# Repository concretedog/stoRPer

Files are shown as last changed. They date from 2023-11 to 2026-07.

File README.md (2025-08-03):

# 

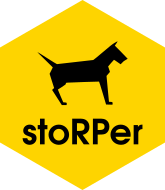
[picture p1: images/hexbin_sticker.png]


stoRPer, a modular adaptable AWD Pico based robot rover

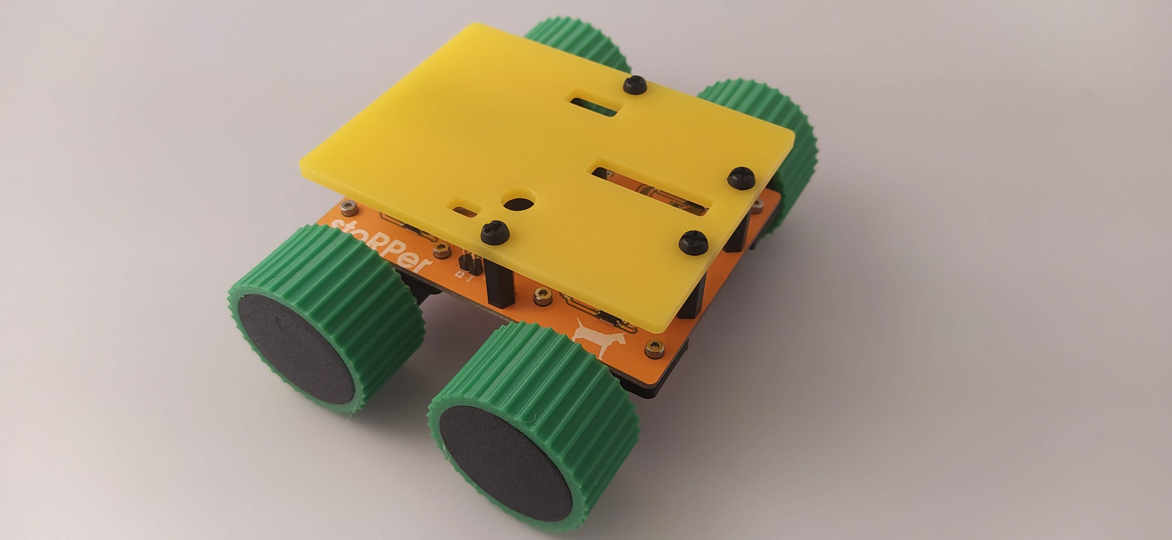
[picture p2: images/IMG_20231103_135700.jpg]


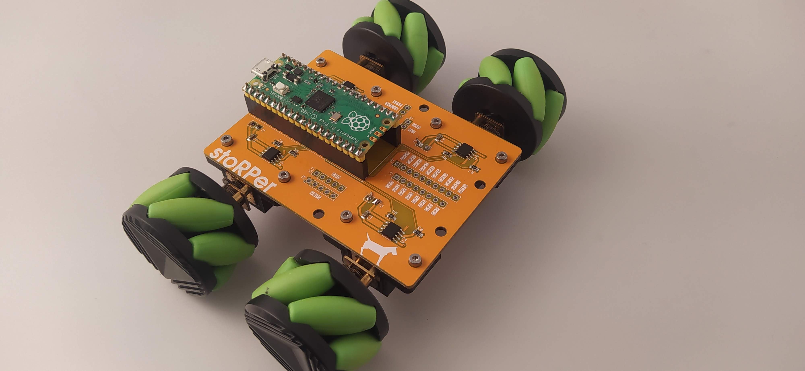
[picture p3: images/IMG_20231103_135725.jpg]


[Check out the youtube video](https://youtu.be/Y8ddx1Og3Xw?feature=shared) with details about the design and the design thinking, at the moment it's probably the best documentation! 

Basic Bill Of Materials, This is just a guide for a basic build as you could build up the PCB in any way you can imagine!

- The PCB, Available on [Tindie](https://www.tindie.com/products/concreted0g/storper/)
- 4* N20 metal gear motors in a gear ratio of your choice rated up to 6V. <br />
- 4* 3D printed motor mount clips to attach the motors (files in the 3D models section or periodically available on the tindie listing as an options)<br />
- 8* 6mm M2 bolts and nuts to attach motor mounts.<br />
- A raspberry pi Pico or Pico W, or equivalent footprint microcontroller board.<br />
- Some N20 compatible wheels (either commercial or home brew/3D printed)<br />
- Some kind of power supply (simplest is a small USB pack, other options are a 14500 or 18650 cell wired into the power input)<br />
- Semi optional, an upper deck to attach power supply too. (Inkscape files for Lasercutting or CNC or heck, cutting out with a saw, are in the Deck Drawing folder, or available lasercut on the Tindie listing)<br />

But that's just a guide, you could use different items or design to the basic PCB/chassis in different ways. <br />

All the KiCad files in the repo were originally made in version 7.xx. 

**Update 28-05-2024**

Added an Addons folder which currently contains 2 new PCB designs. <br />

Bumper can receive an ultrasonic module (HC-SR04) and also have 2 bump switches connected. <br />
The Kludge Deck conforms to the StoRPer main PCB layout with lots of prototyping space and extra holes for mounting stuff! <br />

Bumpers can be added above or below the main PCB with lots of different mount options. Therefore you might need to buy a range of standoffs to accomodate and support your design. If however you have access to a 3D printer there is a FreeCAD file in the 3D models section called STANDOFFS which you can simply adjust the length of a standoff tube that will slot over an M3 bolt. You can make custom lengths to suit your build. 

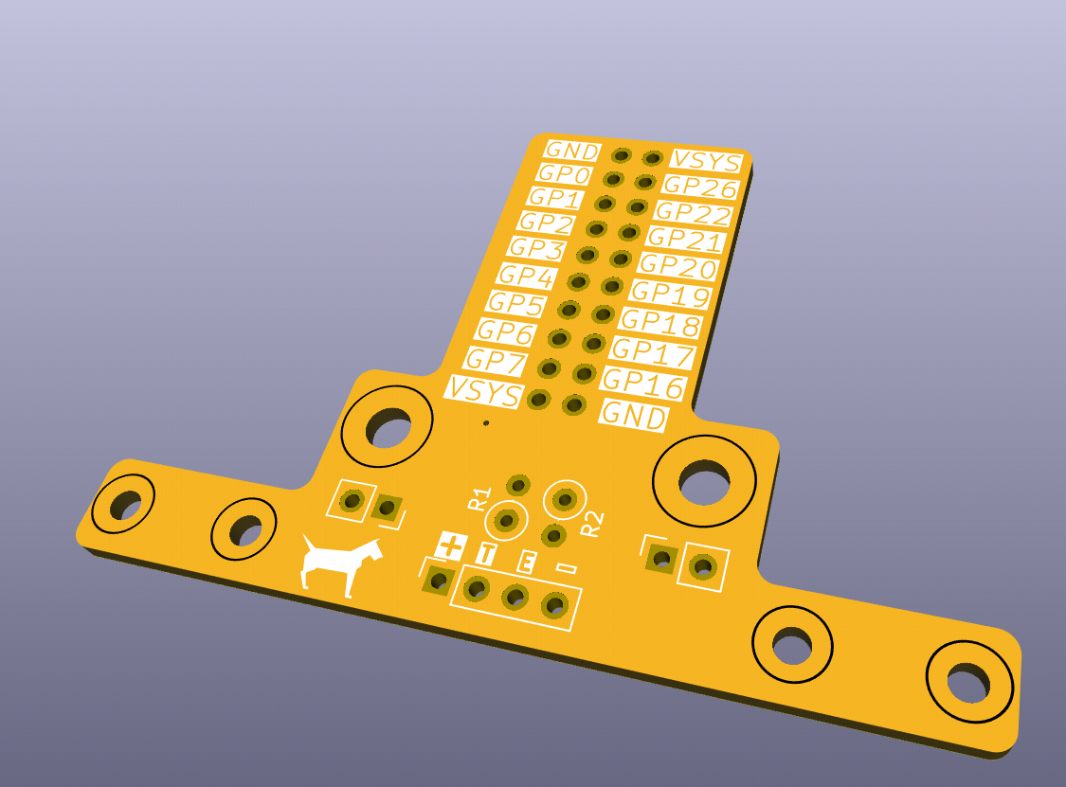
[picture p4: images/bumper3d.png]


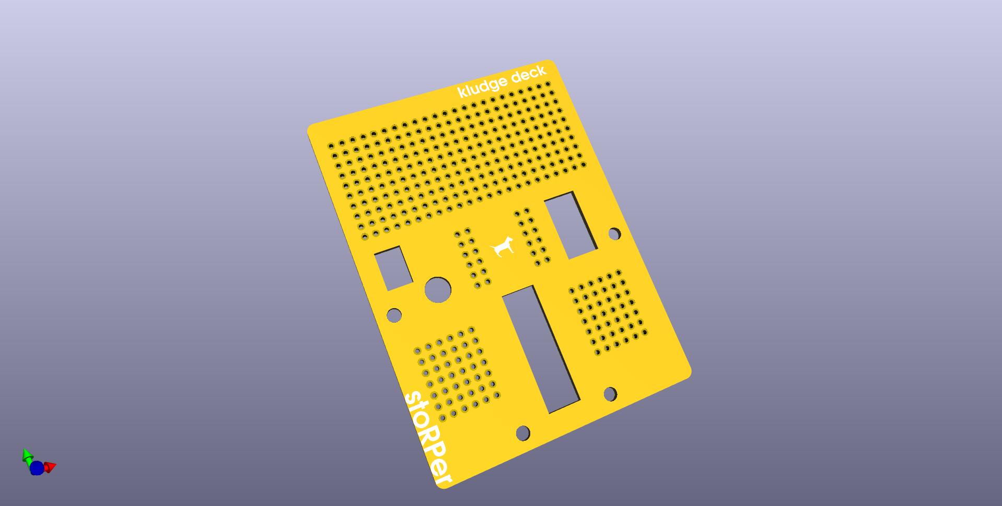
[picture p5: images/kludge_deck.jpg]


**Tiny Update 29-06-25**

Added a small hex adaptor part to the 3D models section. I ran a workshop recently and wanted to use more affordable mecanum wheels and found some cheap 48mm mecanum wheels available on places like aliexpress etc. However they have a hexagonal axle mount. After numerous iterations and dialling in the 3D printing I made a super simple slip on adaptor part that sits inside the wheel and slots on snugly to the N20 motor mount. Useful for stoRPer of course, but useful for any N20 motor project. 

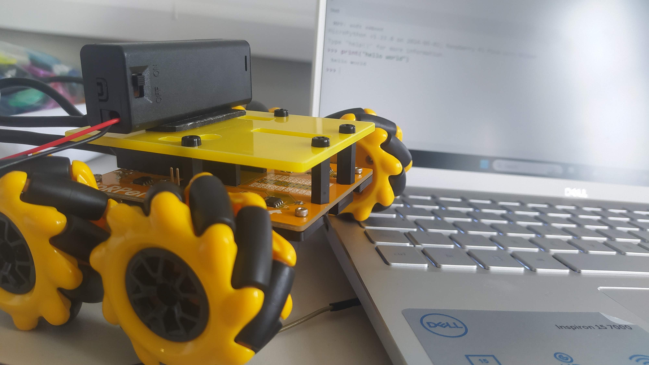
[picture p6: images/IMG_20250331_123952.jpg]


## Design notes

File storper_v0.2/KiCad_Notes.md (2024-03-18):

KiCad design originally made in version 7.xx <br />
In the main project the motor drivers are placed in hierarchical sheets. This is as I was writing a tutorial on Hierarchical sheets at the time!<br />
In the schmatics.pdf the Motor driver sections are all in the main sheet for easier reading. <br />

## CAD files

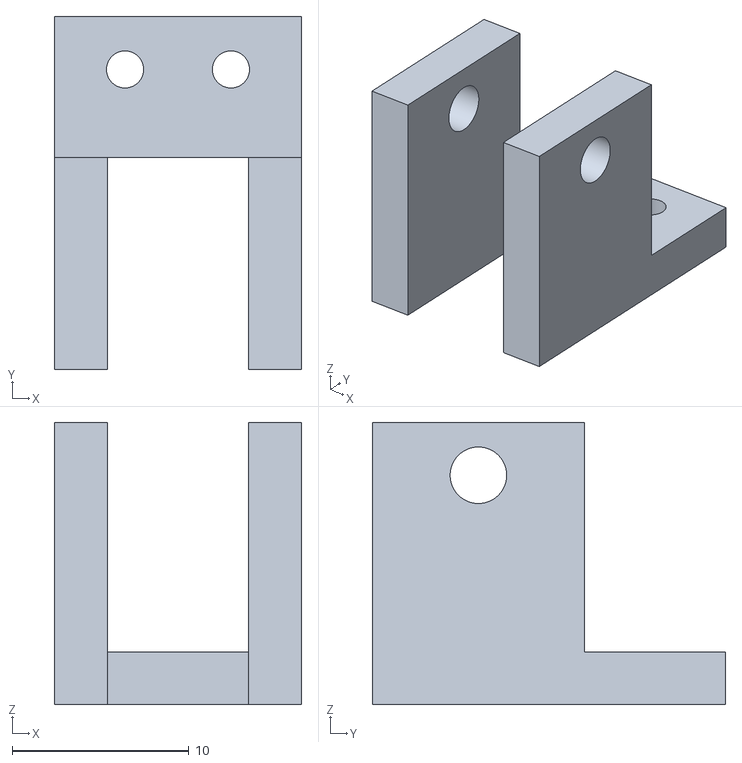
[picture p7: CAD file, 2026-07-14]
3D_Models/storper_tripod_rear_bracket.stl
14.0 x 20.0 x 16.0

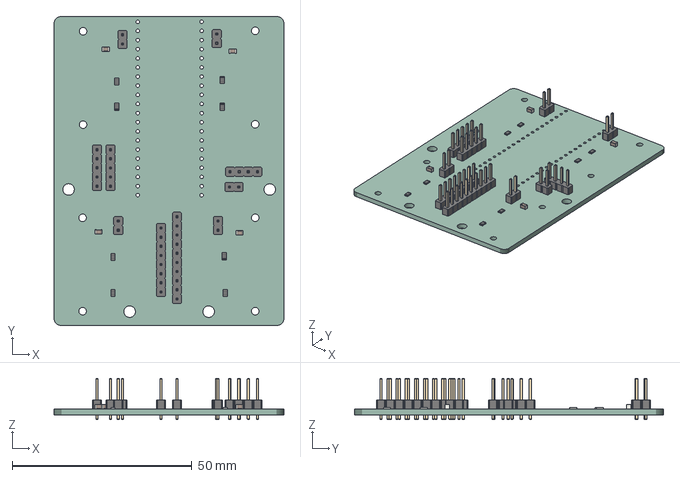
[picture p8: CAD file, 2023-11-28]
storper_v0.2/storper_v0.2.step
64.0 x 86.0 x 11.5 mm
storper_breakout PCB

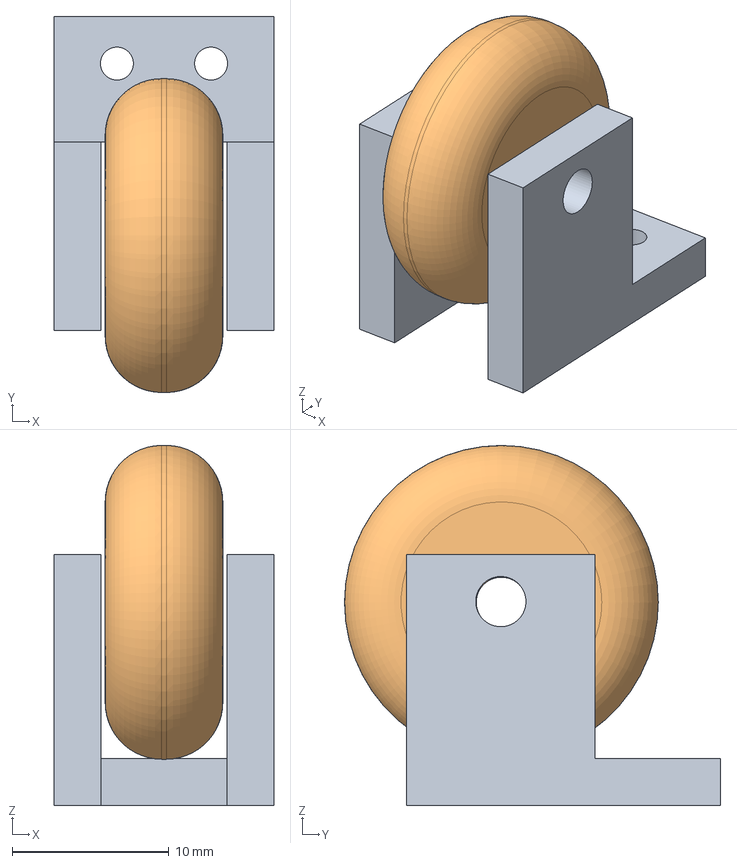
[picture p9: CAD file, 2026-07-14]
3D_Models/storper_tripod_rear_wheel.FCStd
14.0 x 24.0 x 23.0 mm

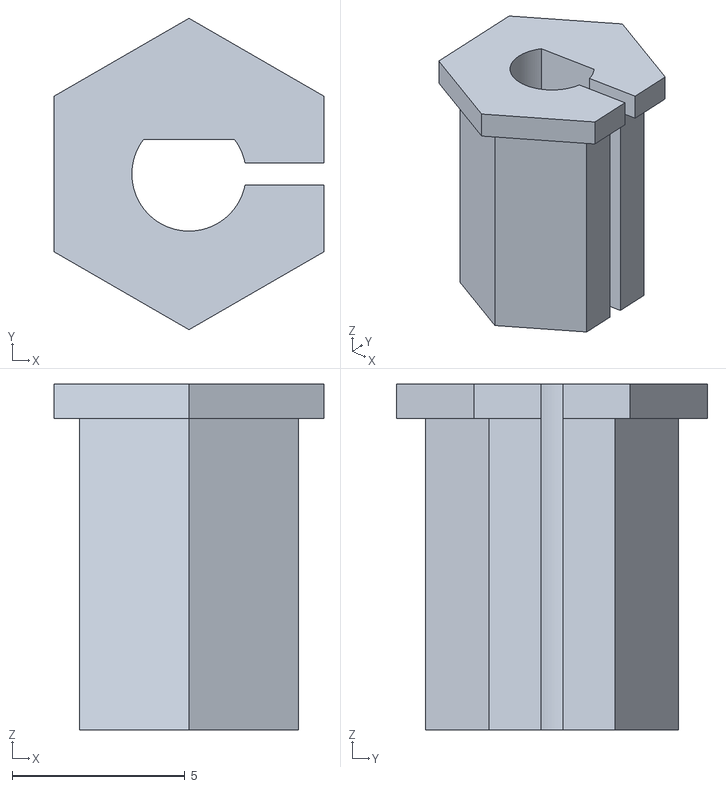
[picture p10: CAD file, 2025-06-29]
3D_Models/hex_wheeladaper.stl
7.79 x 9.00 x 10.0

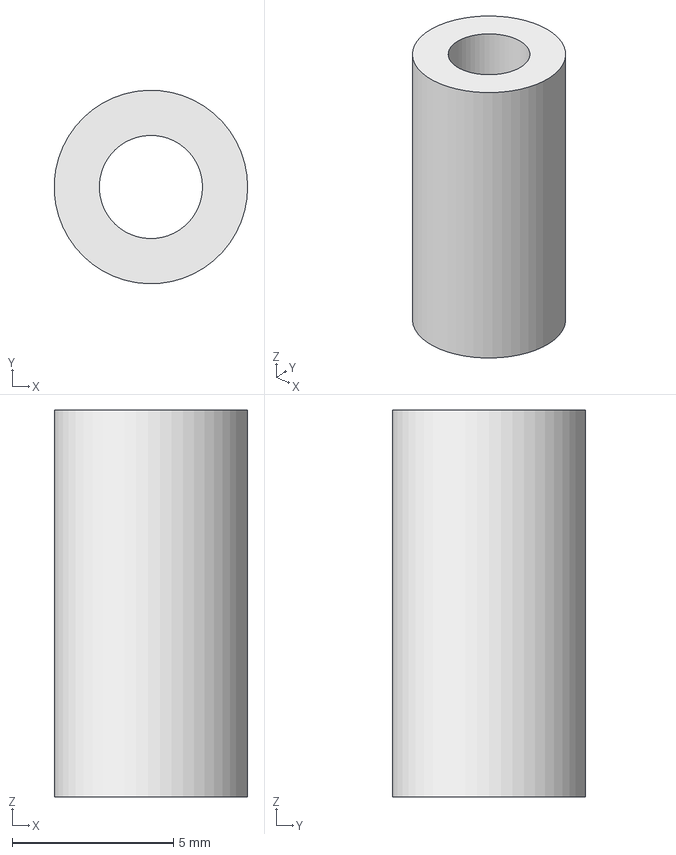
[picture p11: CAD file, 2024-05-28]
3D_Models/STANDOFF.FCStd
5.99 x 6.00 x 12.0 mm

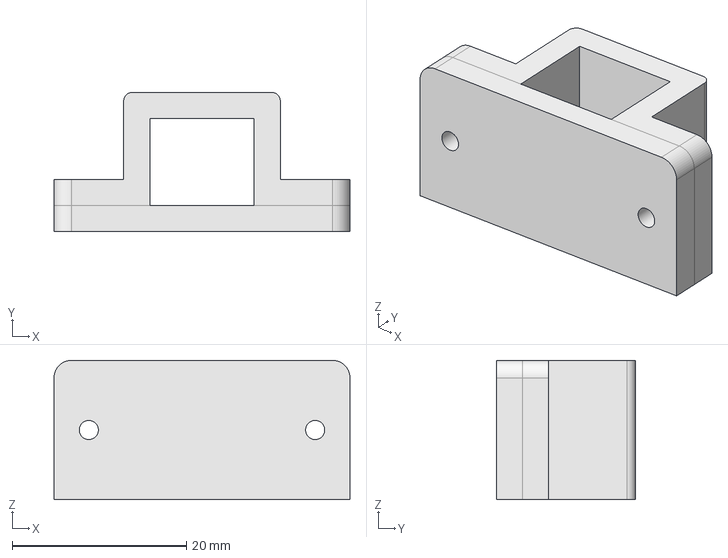
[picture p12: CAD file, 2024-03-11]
3D_Models/standoff_N20_Motor_clamp_TPU.FCStd
34.0 x 16.0 x 16.0 mm

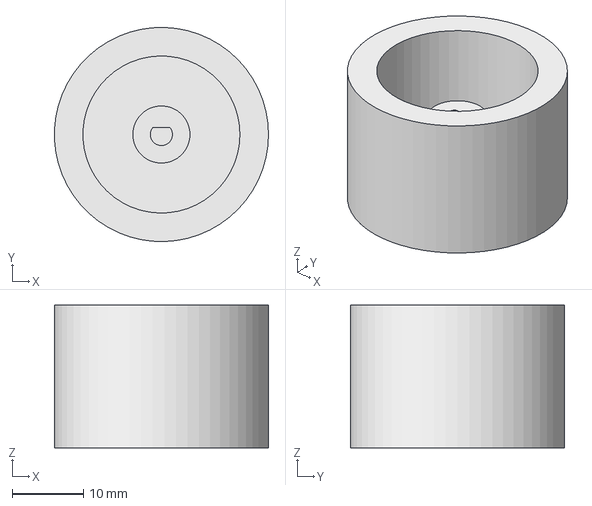
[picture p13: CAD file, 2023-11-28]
3D_Models/storper_standard_wheel.FCStd
30.0 x 30.0 x 20.0 mm

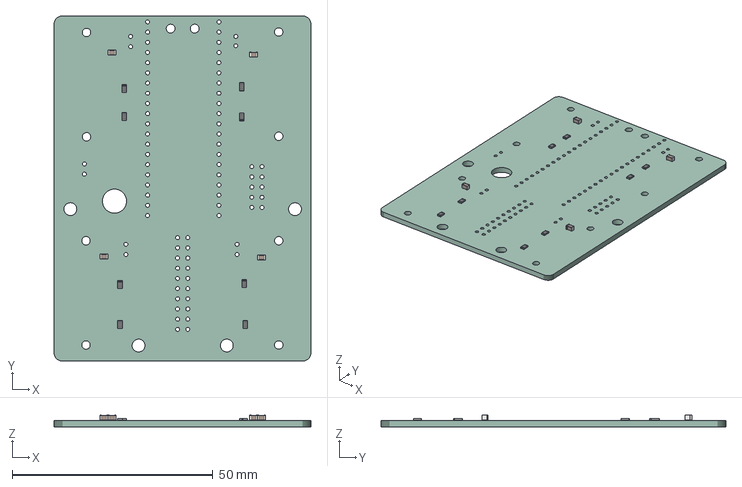
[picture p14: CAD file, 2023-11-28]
3D_Models/storper_v02_PCB.step
64.0 x 86.0 x 2.90 mm
storper_release_candidate PCB

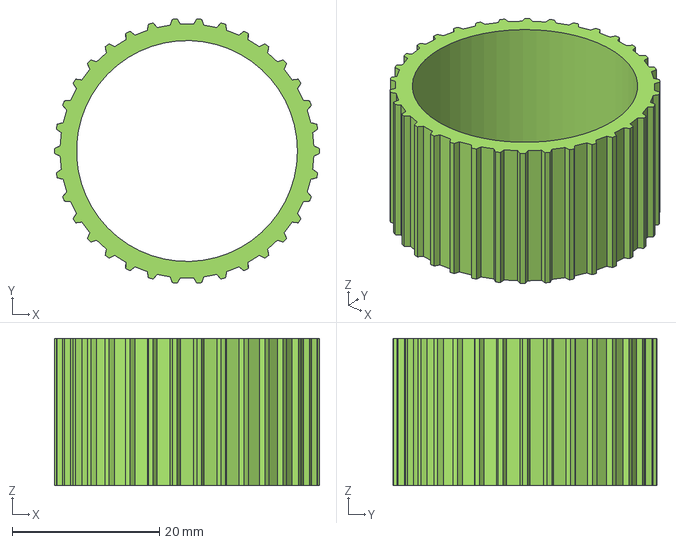
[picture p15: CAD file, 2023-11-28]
3D_Models/stoRPer_standard_wheel_tyre.FCStd
36.0 x 35.9 x 20.0 mm

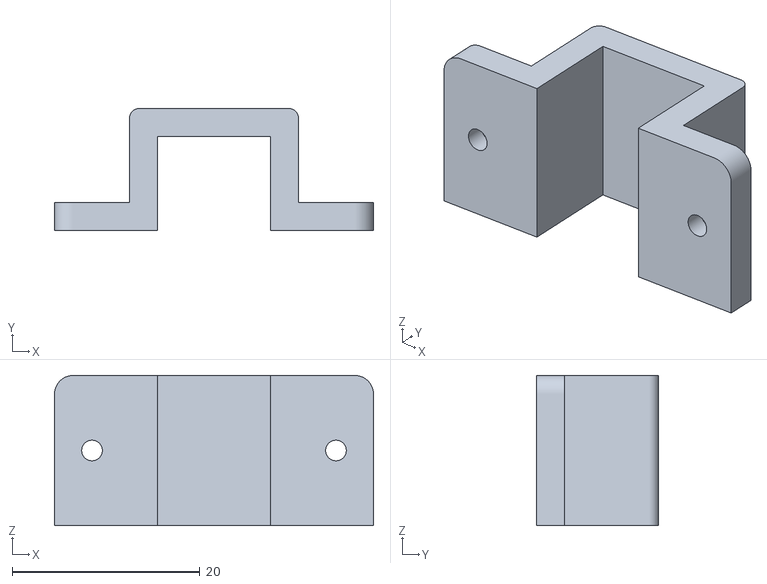
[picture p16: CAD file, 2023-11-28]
3D_Models/N20_clamp.stl
34.0 x 13.0 x 16.0

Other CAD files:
3D_Models/hex_wheel_adapter.FCStd
3D_Models/N20_Motor_Clamp.FCStd
3D_Models/standoff_N20_Motor_clamp_TPU.stl
3D_Models/stoRPer_standard_wheel_tyre.stl
3D_Models/storper_standard_wheel.stl
3D_Models/storper_tripod_rear_wheel.stl

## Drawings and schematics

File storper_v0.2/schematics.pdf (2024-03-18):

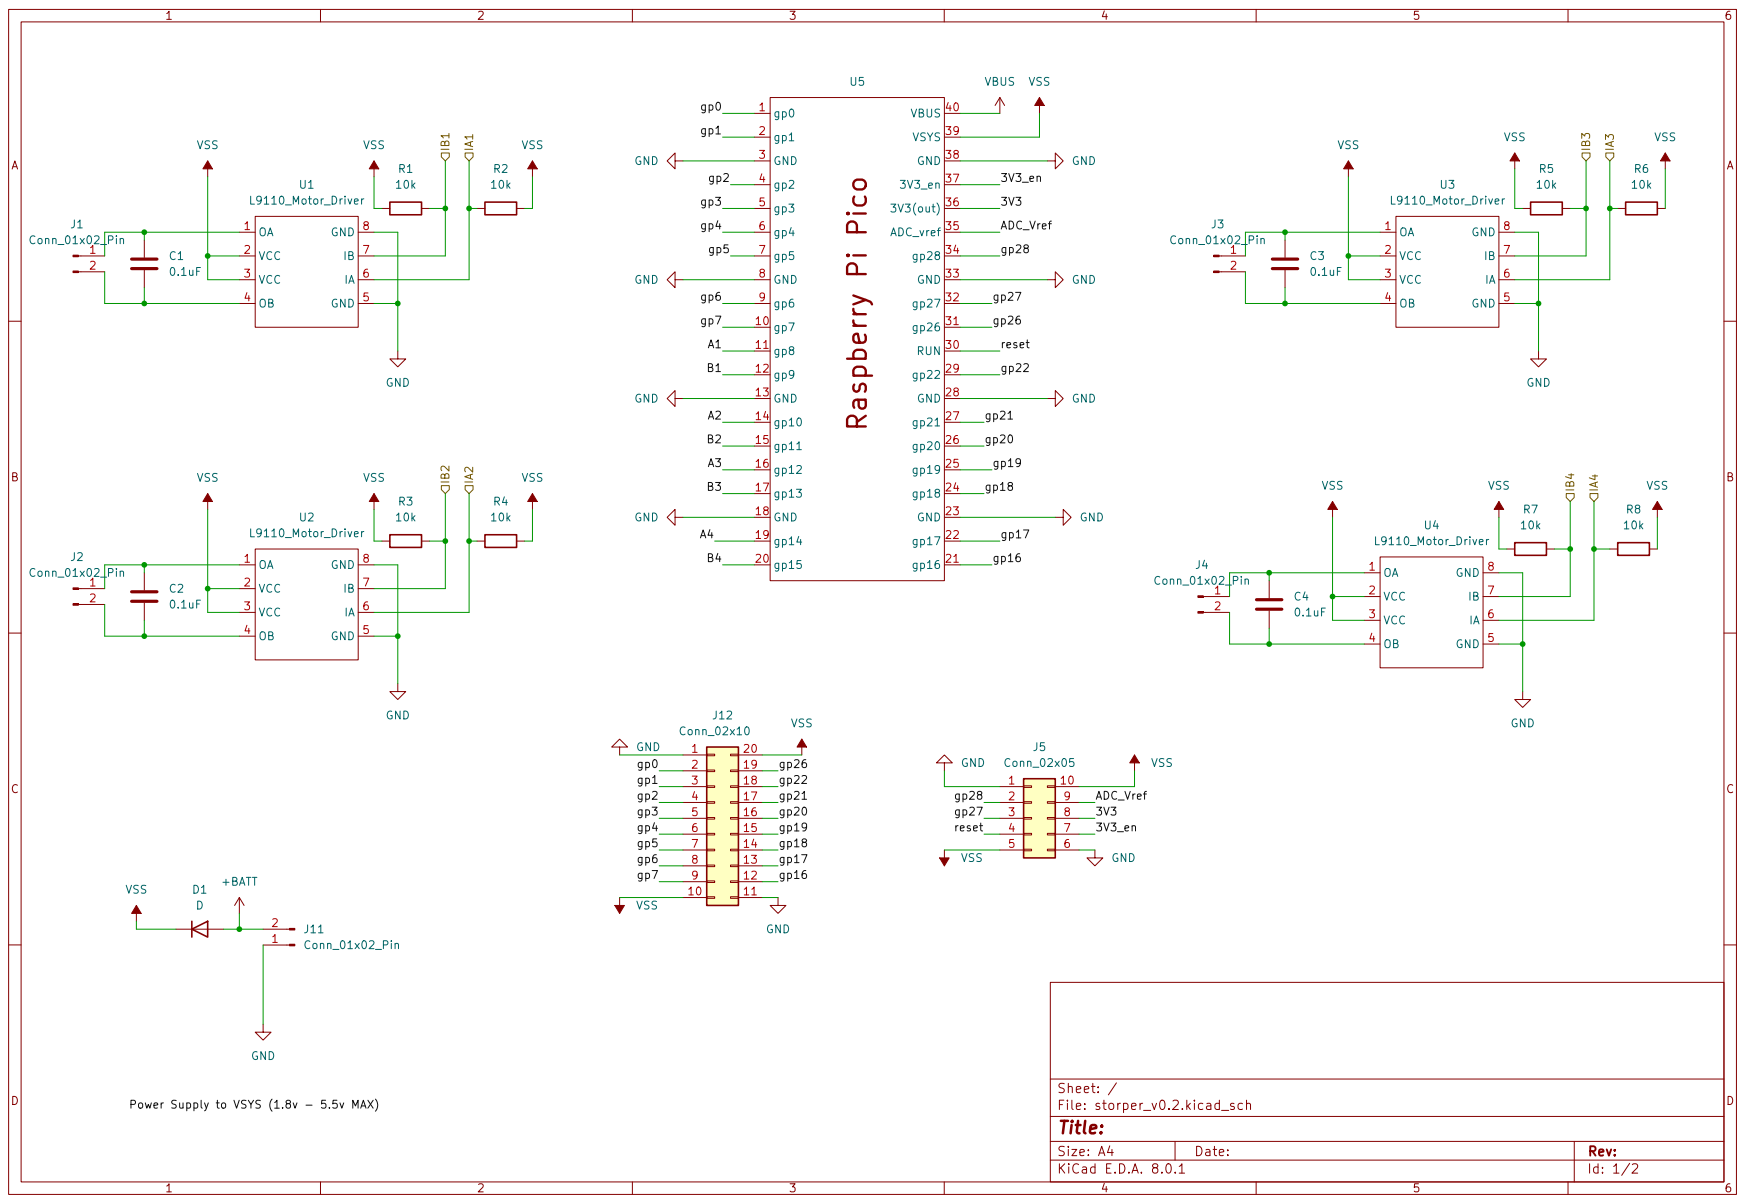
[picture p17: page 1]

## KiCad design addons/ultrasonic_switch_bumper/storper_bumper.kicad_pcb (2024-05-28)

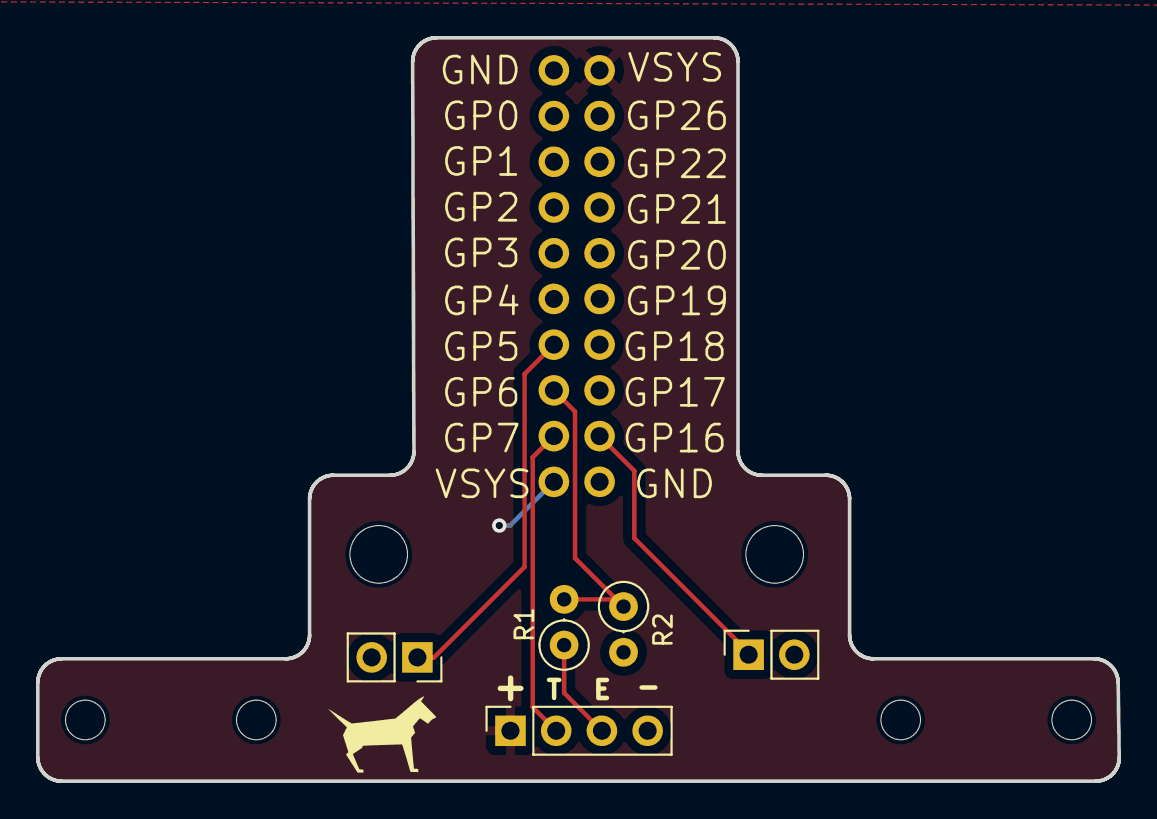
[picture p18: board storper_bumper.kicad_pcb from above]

Board: 2 copper layers, 60.1 x 41.3 mm, 6 parts (0 on the bottom side), 7 nets.

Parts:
J1: HRS04; PinSocket_1x04_P2.54mm_Vertical
J2, J3: Conn_01x02_Pin; PinSocket_1x02_P2.54mm_Vertical
J12: Conn_02x10_Counter_Clockwise; stoRPer_breakout
R1, R2: R; R_Axial_DIN0207_L6.3mm_D2.5mm_P2.54mm_Vertical

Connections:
/gp5: J2.1, J12.7
/gp6: J12.8, R1.2, R2.1
/gp7: J1.2, J12.9
/gp16: J3.1, J12.12
GND: J1.4, J2.2, J3.2, J12.1, J12.11, R2.2
unnamed: J1.3, R1.1
VSS: J1.1, J12.10, J12.20

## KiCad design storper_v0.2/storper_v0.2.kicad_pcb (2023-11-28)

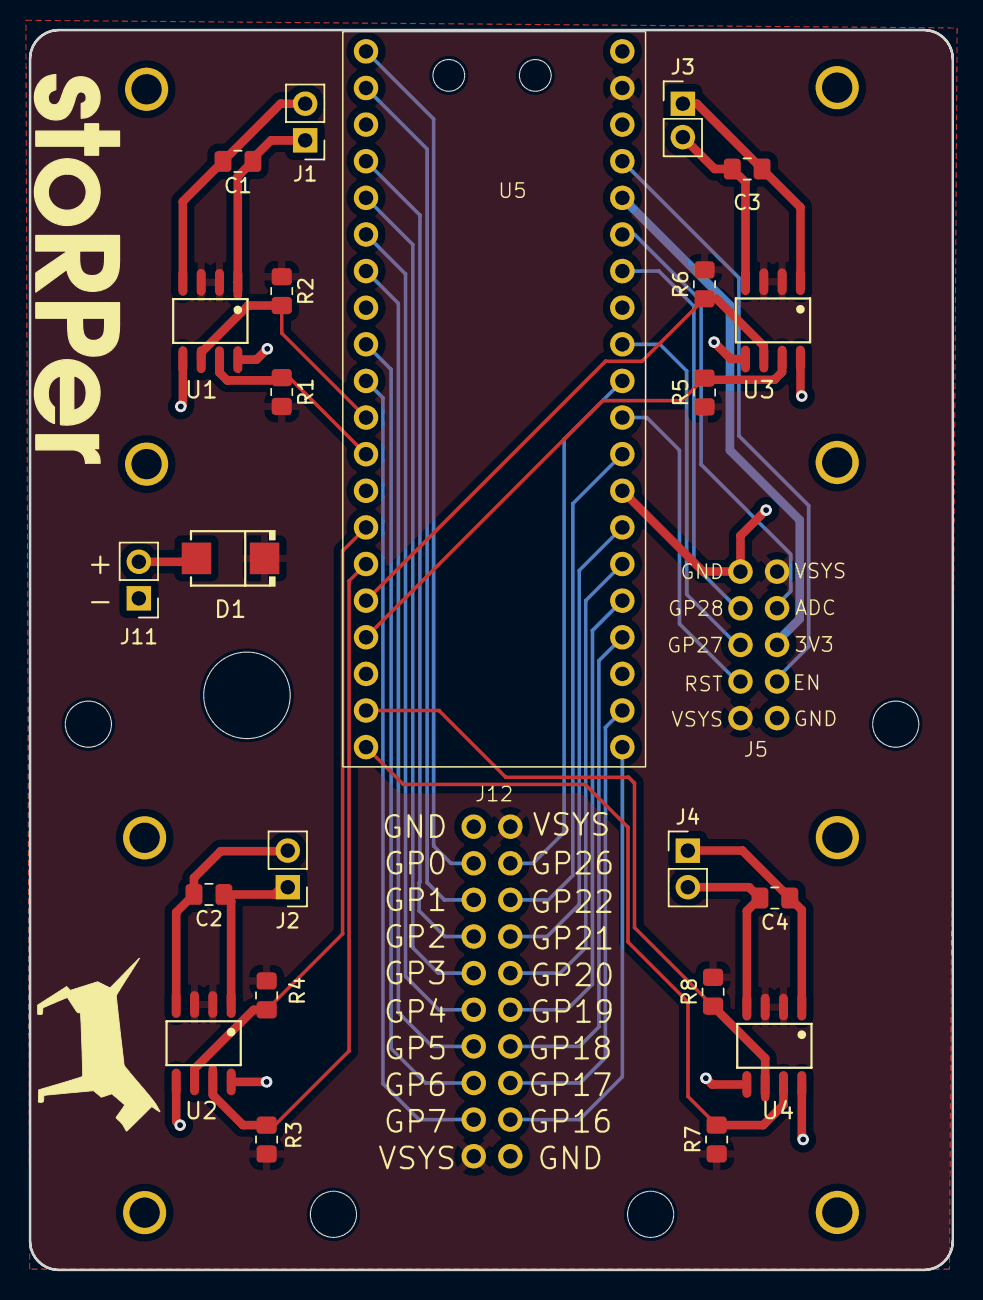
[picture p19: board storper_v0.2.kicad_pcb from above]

Board: 2 copper layers, 64.0 x 86.0 mm, 25 parts (0 on the bottom side), 41 nets.

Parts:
C1, C2, C3, C4: 0.1uF; C_0805_2012Metric_Pad1.18x1.45mm_HandSolder
D1: D; Diode_Schottky_SMB(DO-214AA)
J1, J2, J3, J4, J11: Conn_01x02_Pin; PinHeader_1x02_P2.54mm_Vertical
J5: Conn_02x05_Counter_Clockwise; StoRPer_small_breakout
J12: Conn_02x10_Counter_Clockwise; stoRPer_breakout
R1, R2, R3, R4, R5, R6, R7, R8: 10k; R_0805_2012Metric_Pad1.20x1.40mm_HandSolder
U1, U2, U3, U4: L9110_Motor_Driver; L9110S_SOP-8_L4.9-W3.9-P1.27-LS6.0-BL
U5: RP_Pico

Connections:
+BATT: D1.2 (A), J11.2
/3V3: J5.8, U5.36 (3V3(out))
/3V3_en: J5.7, U5.37 (3V3_en)
/A1: R2.1, U1.6 (IA), U5.11 (gp8)
/A2: R4.1, U2.6 (IA), U5.14 (gp10)
/A3: R6.1, U3.6 (IA), U5.16 (gp12)
/A4: R8.1, U4.6 (IA), U5.19 (gp14)
/ADC_Vref: J5.9, U5.35 (ADC_vref)
/B1: R1.2, U1.7 (IB), U5.12 (gp9)
/B2: R3.2, U2.7 (IB), U5.15 (gp11)
/B3: R5.2, U3.7 (IB), U5.17 (gp13)
/B4: R7.2, U4.7 (IB), U5.20 (gp15)
/gp0: J12.2, U5.1 (gp0)
/gp1: J12.3, U5.2 (gp1)
/gp2: J12.4, U5.4 (gp2)
/gp3: J12.5, U5.5 (gp3)
/gp4: J12.6, U5.6 (gp4)
/gp5: J12.7, U5.7 (gp5)
/gp6: J12.8, U5.9 (gp6)
/gp7: J12.9, U5.10 (gp7)
/gp16: J12.12, U5.21 (gp16)
/gp17: J12.13, U5.22 (gp17)
/gp18: J12.14, U5.24 (gp18)
/gp19: J12.15, U5.25 (gp19)
/gp20: J12.16, U5.26 (gp20)
/gp21: J12.17, U5.27 (gp21)
/gp22: J12.18, U5.29 (gp22)
/gp26: J12.19, U5.31 (gp26)
/gp27: J5.3, U5.32 (gp27)
/gp28: J5.2, U5.34 (gp28)
/reset: J5.4, U5.30 (RUN)
GND: J5.1, J5.6, J11.1, J12.1, J12.11, U1.5 (GND), U1.8 (GND), U2.5 (GND), U2.8 (GND), U3.5 (GND), U3.8 (GND), U4.5 (GND), U4.8 (GND), U5.3 (GND), U5.8 (GND), U5.13 (GND), U5.18 (GND), U5.23 (GND), U5.28 (GND), U5.33 (GND), U5.38 (GND)
unnamed: C1.1, J1.1, U1.1 (OA)
unnamed: C1.2, J1.2, U1.4 (OB)
unnamed: C2.1, J2.1, U2.1 (OA)
unnamed: C2.2, J2.2, U2.4 (OB)
unnamed: C3.1, J3.1, U3.1 (OA)
unnamed: C3.2, J3.2, U3.4 (OB)
unnamed: C4.1, J4.1, U4.1 (OA)
unnamed: C4.2, J4.2, U4.4 (OB)
VSS: D1.1 (K), J5.5, J5.10, J12.10, J12.20, R1.1, R2.2, R3.1, R4.2, R5.1, R6.2, R7.1, R8.2, U1.2 (VCC), U1.3 (VCC), U2.2 (VCC), U2.3 (VCC), U3.2 (VCC), U3.3 (VCC), U4.2 (VCC), U4.3 (VCC), U5.39 (VSYS)

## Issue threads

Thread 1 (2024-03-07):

BOM ?

nathmo, 2024-03-07:
Hi, I'm really interested in your mecanum wheel for a totally unrelated project (Kerbal space program Navball replica) and I would like to know if the BOM is somewhere that I missed or if the mecanum are custom-made to find the file :)

It's a really nice project, by the way :)

feiltom, 2024-03-07:
hello, same thing. have you a BOM ?
i see your project on hack a day. very interested for children in  a educational fablab.
Cdt

concretedog, 2024-03-07:
Hi all, thanks for your interest... It's been a busy week! I need to write up a minimal BOM. I guess it's a little variable as you can do different things with the design. I'll add a BOM document to the repo or add details on the readme but for now... You'll need;

The PCB
Some N20 metal gear motors in a gear ratio of your choice rated up to 6V.
Some 3D printed motor mount clips to attach the motors (files in the 3D models section)
8* 6mm M2 bolts and nuts to attach motor mounts.
A raspberry pi Pico or Pico W, or equivalent footprint microcontroller board.
Some N20 compatible wheels (either commercial or home brew/3D printed)
Some kind of power supply (simplest is a small USB pack, other options are a 14500 or 18650 cell wired into the power input)
Semi optional, an upper deck to attach power supply too.

But as I say, that's just a guide, you could use different items or design to the basic PCB/chassis in different ways.

concretedog, 2024-03-07:
> Hi, I'm really interested in your mecanum wheel for a totally unrelated project (Kerbal space program Navball replica) and I would like to know if the BOM is somewhere that I missed or if the mecanum are custom-made to find the file :)
>
> It's a really nice project, by the way :)

Thanks for the kind words. Regarding the Mecanum wheels, they are a commercial item. They are available in lots of places in the UK I bought mine via Pimoroni https://shop.pimoroni.com/products/mecanum-wheels-pack-of-4?variant=31590632063059

I'm sure there are mecanum wheel designs out there for 3D print and assembly as well! Might be worth searching around.

concretedog, 2024-03-07:
Marking this as closed as I've added a brief BOM to the readme.

Closed 2024-03-07.

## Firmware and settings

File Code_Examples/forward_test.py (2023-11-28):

from machine import Pin, PWM
import time

'''
This script is a simple example that drives all motors forward continuously. Commented out in the lower section you can see examples of reversing and turning.  

'''
SPEED = 65025
STOP = 0

RRIGHT_FORWARD_PIN = 8 # Note that you might need to swap the pin numbers over to set the motor rotation correctly depending on how you wire in your motors. 
RRIGHT_REVERSE_PIN = 9

FRIGHT_FORWARD_PIN = 10 
FRIGHT_REVERSE_PIN = 11

FLEFT_FORWARD_PIN = 12
FLEFT_REVERSE_PIN = 13

RLEFT_FORWARD_PIN = 15
RLEFT_REVERSE_PIN = 14

rright_forward = PWM(Pin(RRIGHT_FORWARD_PIN))
rright_reverse = PWM(Pin(RRIGHT_REVERSE_PIN))

fright_forward = PWM(Pin(FRIGHT_FORWARD_PIN))
fright_reverse = PWM(Pin(FRIGHT_REVERSE_PIN))

fleft_forward = PWM(Pin(FLEFT_FORWARD_PIN))
fleft_reverse = PWM(Pin(FLEFT_REVERSE_PIN))

rleft_forward = PWM(Pin(RLEFT_FORWARD_PIN))
rleft_reverse = PWM(Pin(RLEFT_REVERSE_PIN))

def spin_wheel(pwm):
        pwm.duty_u16(SPEED)
        pwm.freq(500)
        
def stop_wheel(pwm):
        pwm.duty_u16(STOP)
        pwm.freq(500)
      

while True:
    #All forward 
    spin_wheel(rright_forward)
    spin_wheel(fright_forward)
    spin_wheel(fleft_forward)
    spin_wheel(rleft_forward)
    
    
 '''   
    time.sleep(4)
    stop_wheel(rright_forward)
    stop_wheel(fright_forward)
    stop_wheel(fleft_forward)
    stop_wheel(rleft_forward)
    time.sleep(1)
    
    
    #All reverse 4 seconds
    spin_wheel(rright_reverse)
    spin_wheel(fright_reverse)
    spin_wheel(fleft_reverse)
    spin_wheel(rleft_reverse)
    time.sleep(4)
    stop_wheel(rright_reverse)
    stop_wheel(fright_reverse)
    stop_wheel(fleft_reverse)
    stop_wheel(rleft_reverse)
    time.sleep(1)
    
    #Sideways right 4 seconds
    spin_wheel(rright_reverse)
    spin_wheel(fright_forward)
    spin_wheel(fleft_forward)
    spin_wheel(rleft_reverse)
    time.sleep(4)
    stop_wheel(rright_reverse)
    stop_wheel(fright_forward)
    stop_wheel(fleft_forward)
    stop_wheel(rleft_reverse)
    time.sleep(1)
    
    #All forward 4 seconds
    spin_wheel(rright_forward)
    spin_wheel(fright_forward)
    spin_wheel(fleft_forward)
    spin_wheel(rleft_forward)
    time.sleep(4)
    stop_wheel(rright_forward)
    stop_wheel(fright_forward)
    stop_wheel(fleft_forward)
    stop_wheel(rleft_forward)
    time.sleep(1)
    
    #Sideways left 4 seconds
    spin_wheel(rright_forward)
    spin_wheel(fright_reverse)
    spin_wheel(fleft_reverse)
    spin_wheel(rleft_forward)
    time.sleep(4)
    stop_wheel(rright_forward)
    stop_wheel(fright_reverse)
    stop_wheel(fleft_reverse)
    stop_wheel(rleft_forward)
    time.sleep(1)
    
    #All reverse 4 seconds
    spin_wheel(rright_reverse)
    spin_wheel(fright_reverse)
    spin_wheel(fleft_reverse)
    spin_wheel(rleft_reverse)
    time.sleep(4)
    stop_wheel(rright_reverse)
    stop_wheel(fright_reverse)
    stop_wheel(fleft_reverse)
    stop_wheel(rleft_reverse)
    time.sleep(1)
'''    

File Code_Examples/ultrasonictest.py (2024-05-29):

#Basic example of getting the HCSR04 sensor operational and reporting a distance to the REPL
# This example slighlty teaked from an example found on Electrocredible.com,


from machine import Pin
import time
trigger_pin=7
echo_pin=6
trigger=Pin(trigger_pin, Pin.OUT)
echo=Pin(echo_pin, Pin.IN)

while True:
    trigger.high()
    time.sleep_us(11)
    trigger.low()
    while (echo.value()==0):
        pass #wait for echo
    lastreadtime=time.ticks_us() # record the time when signal went HIGH
    while (echo.value()==1):
        pass #wait for echo to finish
    echotime=time.ticks_us()-lastreadtime
    if echotime>37000:
        print("No obstacle detected")
    else:
        distance = (echotime * 0.034) / 2
        print("Obstacle distance= {}cm".format(distance))
    time.sleep(1)

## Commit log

2023-11-28 Add files via upload
    Added 3D models
    [N20_Motor_Clamp.FCStd, N20_clamp.stl, stoRPer_standard_wheel_tyre.FCStd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]
2023-11-28 Add files via upload
    Added KiCad project
    [L9910_Motor_Driver_1.kicad_sch, L9910_Motor_Driver_2.kicad_sch, L9910_Motor_Driver_3.kicad_sch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]
2024-03-07 Update added brief BOM to README.md
2024-03-11 added a standoff motor mount FreeCAD model
    [standoff_N20_Motor_clamp_TPU.FCStd]
2024-03-18 Update README_added KiCad version note.md
2024-03-18 Added schematic PDF.
2025-06-29 adding hex wheel adaptor for cheap mecanum wheels
    [hex_wheel_adapter.FCStd]
2025-06-29 uploading stl for hex wheel adaptor
    [hex_wheeladaper.stl]
2025-06-29 Update README.md n20 hex mounts
2025-08-03 Render BOM as a list for slightly better readability
2026-07-14 Add files via upload
    rear wheel assembly freecad file for cheap 3 wheel version of storper, uses small holes under the pico mount
    [storper_tripod_rear_wheel.FCStd]
2026-07-14 Add files via upload
    stl files added for storper tripod rear wheel for 3 wheel affordable storper builds
    [storper_tripod_rear_bracket.stl, storper_tripod_rear_wheel.stl]
2026-10-22 added 3 wheel stoRPer example script
